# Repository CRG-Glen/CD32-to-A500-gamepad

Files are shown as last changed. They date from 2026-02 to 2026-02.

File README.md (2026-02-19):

# CD32 to The A500 Gamepad

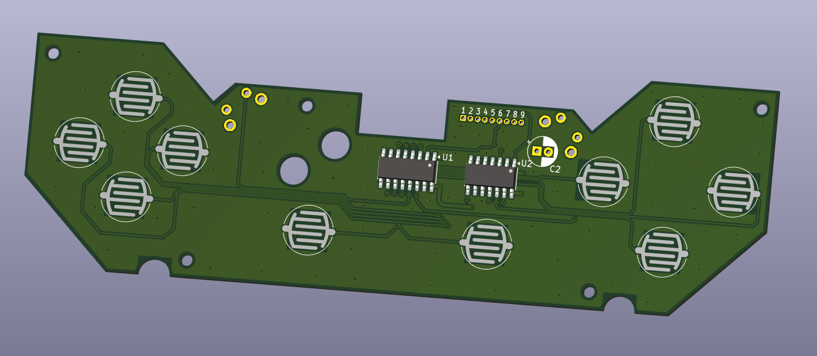
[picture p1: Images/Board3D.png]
PCB


This is a replacement PCB for The A500 gamepad making it a true CD32 pad.

Based on Commodore CD32 gamepad schematics.

YouTube video on the design, assembly and testing of this project can be viewed here - https://youtu.be/vLGpuEnnuxA

## Assembly

Within the JLCPCB folder you will find Gerbers along with a BOM and CPL files suited to LSSC components.

I recommend having the board produced with the EINT finish and get JLC (or equal) to do all SMD work as its 0402 and very fiddly.

You must fit the through hole capacitor yourself (47uF 2mm pin spacing 5mm diameter) as it needs to be folded over onto the PCB.

For the shoulder button switches, you can just take them off the original PCB or the part numbers are below.

You will obviously need a new wire, I'd recommend a simple DB9 extension cable and cut the end off.  The holes labelled 1-9
on the PCB correspond to pins 1-9  on the DB9.  This is at 1.27mm pitch so be careful not to bridge anything!

## Bill of Materials

| Designation | Value | Type |
| --- | --- | --- |
| U1 | 74LS165 | SOIC16 |
| U2 | 74LS125 | SOIC14 |
| R1 | 220ohm 1% | 0402 |
| R10 | 1k ohm 1% | 0402 |
| R11 | 10k ohm 1% | 0402 |
| R15 | 100ohm 1% | 0402 |
| RP1 | 10k 1% | 4x0402 |
| RP2 | 10k 1% | 4x0402 |
| C1 | 100pF | 0402 ceramic |
| C2 | 47uF | 2mm lead spacing 5mm diameter *remember to fold this over* |
| C3 | 1000pF | 0402 ceramic |
| C4 | 0.1uF | 0402 ceramic |
| C5 | 0.1uF | 0402 ceramic |
| FB1 | 1kohm @ 100MHz | 0402 |
| SW9 | PTS645Vx39-2LFS | Tactile SPST Angled Switch *or take this off the old PCB* |
| SW10 | PTS645Vx39-2LFS | Tactile SPST Angled Switch *or take this off the old PCB* |

## License

CERN Open Hardware Licence v2

Do with as you like just don't blame me if your Amiga goes up in smoke!

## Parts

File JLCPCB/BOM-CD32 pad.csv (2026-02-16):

Comment | Designator | Footprint | LCSC | Quantity
0.1uf | C4,C5 | C_0402_1005Metric_Pad0.74x0.62mm_HandSolder | C307331 | 2
100 | R15 | R_0402_1005Metric_Pad0.72x0.64mm_HandSolder | C25076 | 1
1000pf | C3 | C_0402_1005Metric_Pad0.74x0.62mm_HandSolder | C1523 | 1
100pf | C1 | C_0402_1005Metric_Pad0.74x0.62mm_HandSolder | C1546 | 1
10k | R11 | R_0402_1005Metric_Pad0.72x0.64mm_HandSolder | C25744 | 1
10k | RP1,RP2 | R_Array_Concave_4x0402 | C414600 | 2
1k | R10 | R_0402_1005Metric_Pad0.72x0.64mm_HandSolder | C11702 | 1
220 | R1 | R_0402_1005Metric_Pad0.72x0.64mm_HandSolder | C25091 | 1
74LS125 | U2 | SOIC-14_3.9x8.7mm_P1.27mm | C7734 | 1
74LS165 | U1 | SOIC-16_3.9x9.9mm_P1.27mm | C7742 | 1
FerriteBead_Small | FB1 | C_0402_1005Metric_Pad0.74x0.62mm_HandSolder | C32472 | 1
PTS645Vx39-2LFS | SW10,SW9 | SW_Tactile_SPST_Angled_PTS645Vx39-2LFS | C221887 | 2
C BUTTON | SW8 | Button contact 8mm |  | 1
Conn_01x09_Pin | J1 | PinHeader_1x09_P1.27mm_Vertical |  | 1
MIDDLE BUTTON | SW12 | Button contact 8mm |  | 1
UP | SW1 | Button contact 8mm |  | 1
DOWN | SW2 | Button contact 8mm |  | 1
D BUTTON | SW7 | Button contact 8mm |  | 1
LEFT | SW3 | Button contact 8mm |  | 1
RIGHT | SW4 | Button contact 8mm |  | 1
MIDDLE BUTTON | SW11 | Button contact 8mm |  | 1
FIRE BUTTON | SW6 | Button contact 8mm |  | 1
47uf | C2 | CP_Radial_D5.0mm_P2.00mm |  | 1
RIGHT BUTTON | SW5 | Button contact 8mm |  | 1

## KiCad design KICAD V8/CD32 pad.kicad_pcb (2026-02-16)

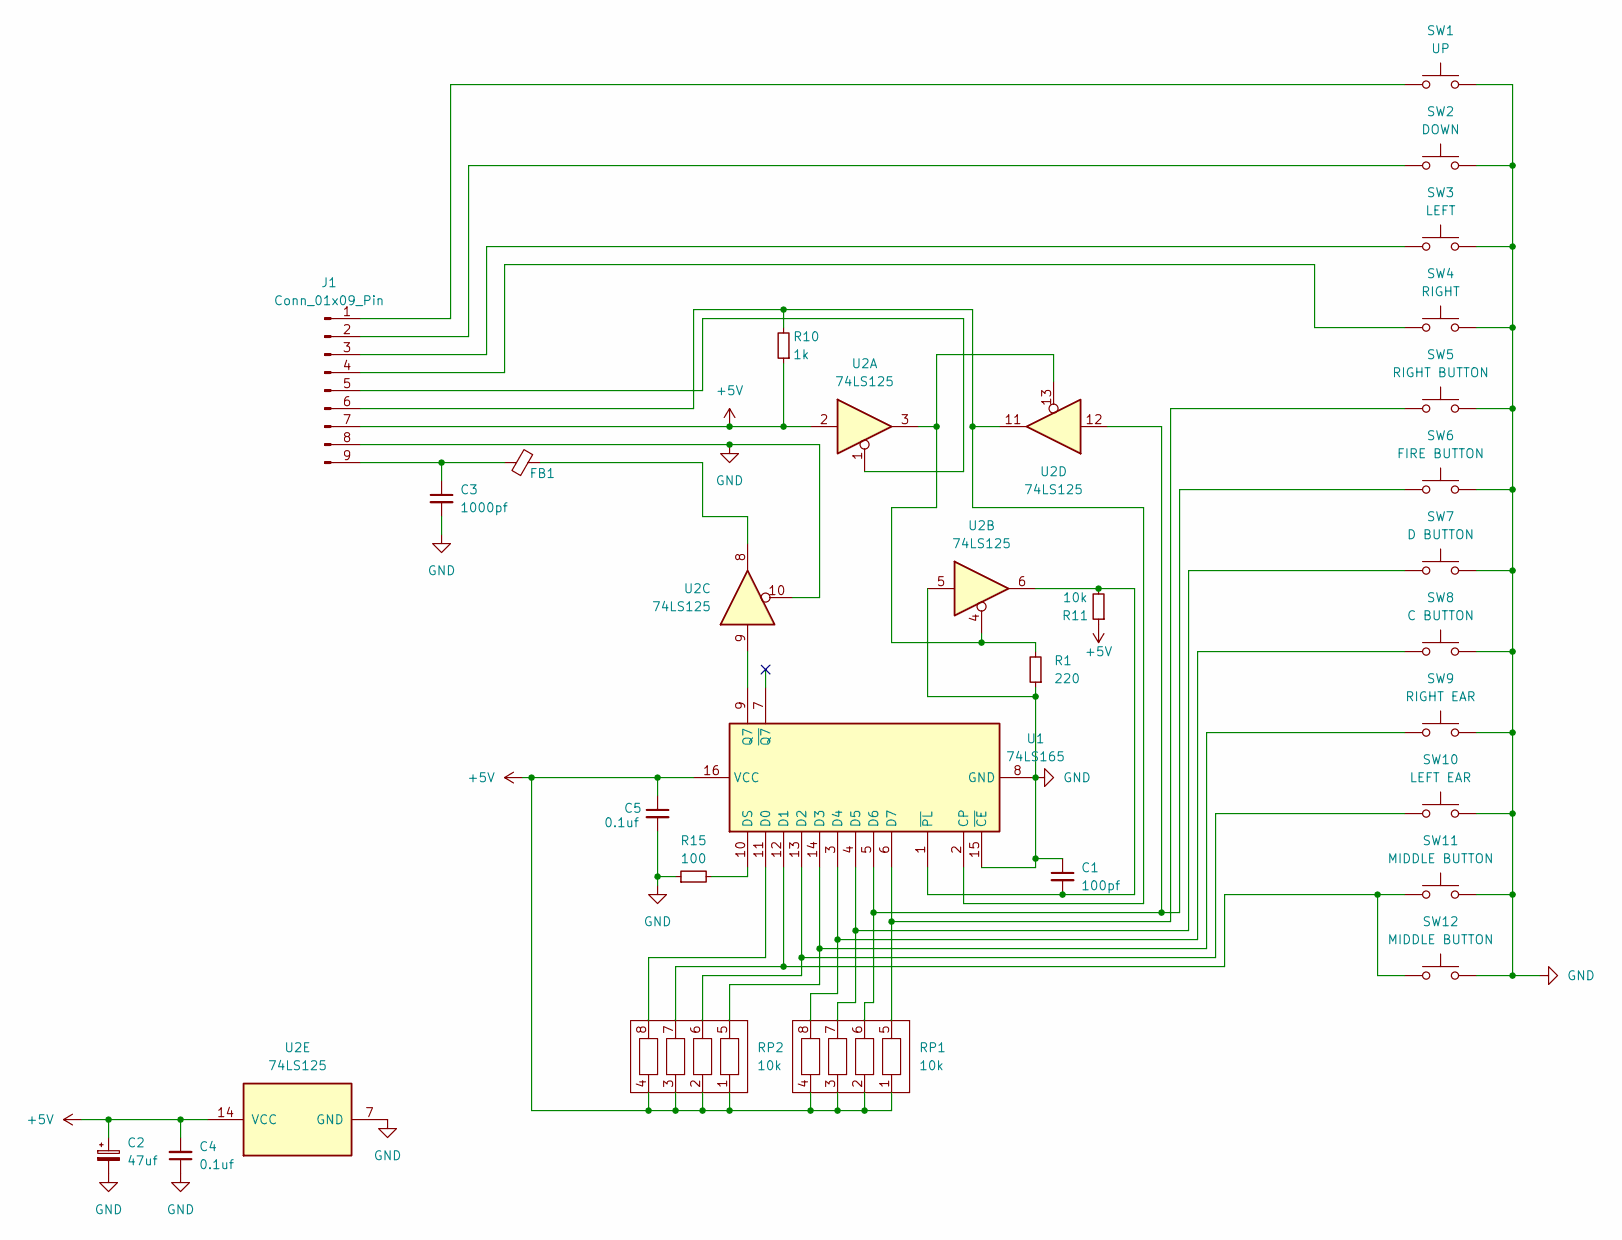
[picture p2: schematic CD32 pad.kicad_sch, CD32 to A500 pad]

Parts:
C1: 100pf; C_0402_1005Metric_Pad0.74x0.62mm_HandSolder; LCSC C1546
C2: 47uf; CP_Radial_D5.0mm_P2.00mm
C3: 1000pf; C_0402_1005Metric_Pad0.74x0.62mm_HandSolder; LCSC C1523
C4, C5: 0.1uf; C_0402_1005Metric_Pad0.74x0.62mm_HandSolder; LCSC C307331
FB1: FerriteBead_Small; C_0402_1005Metric_Pad0.74x0.62mm_HandSolder; LCSC C32472
J1: Conn_01x09_Pin; PinHeader_1x09_P1.27mm_Vertical
R1: 220; R_0402_1005Metric_Pad0.72x0.64mm_HandSolder; LCSC C25091
R10: 1k; R_0402_1005Metric_Pad0.72x0.64mm_HandSolder; LCSC C11702
R11: 10k; R_0402_1005Metric_Pad0.72x0.64mm_HandSolder; LCSC C25744
R15: 100; R_0402_1005Metric_Pad0.72x0.64mm_HandSolder; LCSC C25076
RP1, RP2: 10k; R_Array_Concave_4x0402; LCSC C414600
SW1: UP; Button contact 8mm
SW2: DOWN; Button contact 8mm
SW3: LEFT; Button contact 8mm
SW4: RIGHT; Button contact 8mm
SW5: RIGHT BUTTON; Button contact 8mm
SW6: FIRE BUTTON; Button contact 8mm
SW7: D BUTTON; Button contact 8mm
SW8: C BUTTON; Button contact 8mm
SW9: RIGHT EAR; SW_Tactile_SPST_Angled_PTS645Vx39-2LFS; LCSC C221887
SW10: LEFT EAR; SW_Tactile_SPST_Angled_PTS645Vx39-2LFS; LCSC C221887
SW11, SW12: MIDDLE BUTTON; Button contact 8mm
U1: 74LS165; SOIC-16_3.9x9.9mm_P1.27mm; LCSC C7742
U2: 74LS125; SOIC-14_3.9x8.7mm_P1.27mm; LCSC C7734

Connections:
+5V: C2.1, C4.2, C5.1, J1.7, R10.1, R11.1, RP1.1, RP1.2, RP1.3, RP1.4, RP2.1, RP2.2, RP2.3, RP2.4, U1.16 (VCC), U2.2, U2.14 (VCC)
GND: C1.1, C2.2, C3.2, C4.1, C5.2, J1.8, R1.1, R15.1, SW1.2, SW2.2, SW3.2, SW4.2, SW5.2, SW6.2, SW7.2, SW8.2, SW9.2, SW10.2, SW11.2, SW12.2, U1.8 (GND), U1.15 (~CE), U2.5, U2.7 (GND), U2.10
unnamed: FB1.2, U2.8
unnamed: J1.1, SW1.1
unnamed: J1.2, SW2.1
unnamed: J1.3, SW3.1
unnamed: J1.4, SW4.1
unnamed: J1.5, U2.1
unnamed: J1.6, R10.2, U1.2 (CP), U2.11
unnamed: C3.1, FB1.1, J1.9
unnamed: R1.2, U2.3, U2.4, U2.13
unnamed: RP2.8, U1.11 (D0)
unnamed: RP2.7, SW11.1, SW12.1, U1.12 (D1)
unnamed: RP2.6, SW10.1, U1.13 (D2)
unnamed: RP2.5, SW9.1, U1.14 (D3)
unnamed: RP1.8, SW8.1, U1.3 (D4)
unnamed: RP1.7, SW7.1, U1.4 (D5)
unnamed: RP1.6, SW6.1, U1.5 (D6), U2.12
unnamed: RP1.5, SW5.1, U1.6 (D7)
unnamed: R15.2, U1.10 (DS)
unnamed: U1.9 (Q7), U2.9
unnamed: C1.2, R11.2, U1.1 (~PL), U2.6

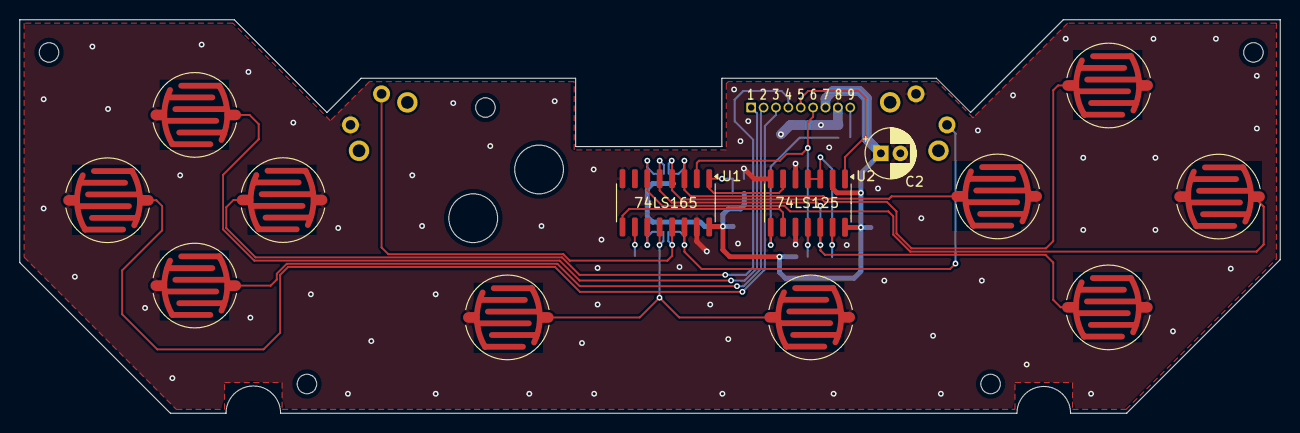
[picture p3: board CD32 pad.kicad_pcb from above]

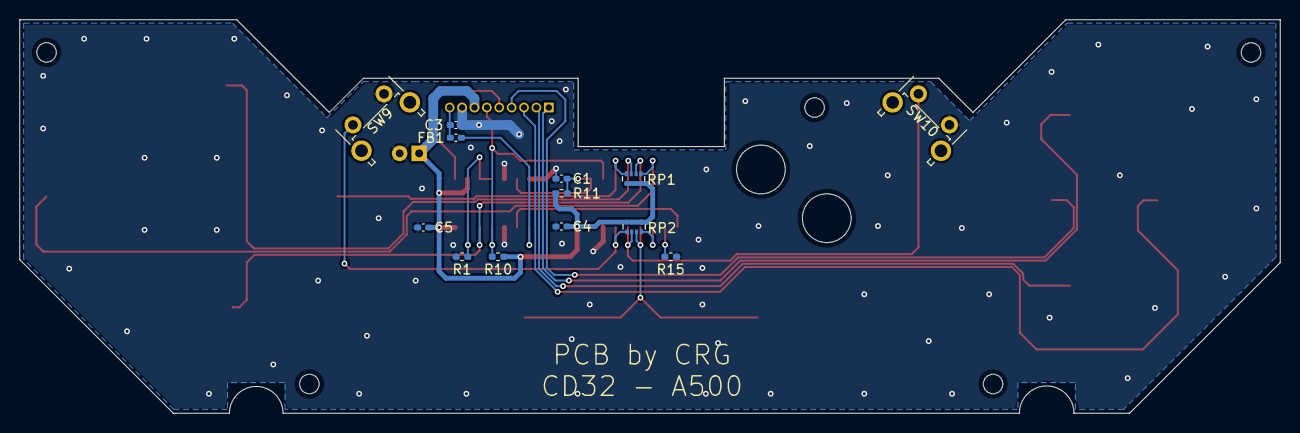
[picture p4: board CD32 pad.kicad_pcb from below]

Board: 2 copper layers, 129.3 x 40.3 mm, 27 parts (13 on the bottom side), 22 nets.

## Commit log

2026-02-16 Released 16-02-26
    [BOM-CD32 pad.csv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]
2026-02-16 Create Board 3D.png
2026-02-16 Rename Board 3D.png to Board3D.png
2026-02-19 BOM revised in readme
